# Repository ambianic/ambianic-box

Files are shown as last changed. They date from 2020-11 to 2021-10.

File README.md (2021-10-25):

# Ambianic Box



Ambianic Box is a 3D printable enclosure for Ambianic Edge. It is intended for Raspberry Pi 4B with a 5MP Raspberry Camera.

[Read the docs](https://docs.ambianic.ai/users/ambianicbox/) for more information on assembling your own Ambianic Box.

<span aligh="left">
  
  
<span>

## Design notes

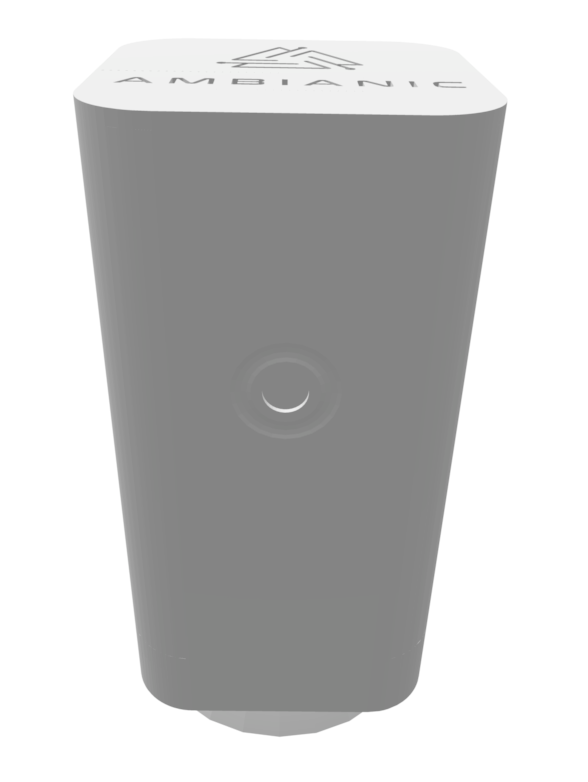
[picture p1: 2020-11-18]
ambianic_box_rendering.png

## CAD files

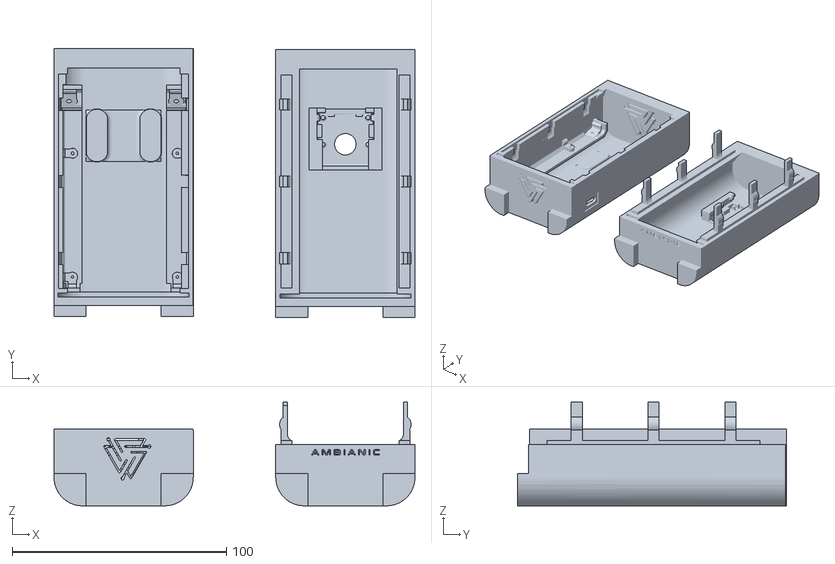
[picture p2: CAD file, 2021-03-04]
Ambianic_Box_for_Home_Care.stl
168.5 x 125.4 x 48.4

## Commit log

2020-11-18 feat: first STL prototype upload
    [Ambianic Box for Home Care.stl]
2020-11-19 fix: delete old version
    [Ambianic Box for Home Care.stl]
2020-11-19 fix: new version
    [Ambianic_Box_for_Home_Care.stl]
2020-11-19 fix: fit issues
    - make base a separate one piece that plugs in vertically. Better print and better support for front and back parts.
    - refine front and back snap shapes.
    - camera mount pins too thick. Camera board holes do not fit in.
    - adjust base pins: don't fit - too big, legs break off easily.
    - Picam mount: lens hole too small, pins too thin - slide out easily, picam board slips out from mount easily
    - Fits don't match for front and back parts
    - Audio and hdmi ports: open holes, don't match with the actual board positions
    [Ambianic_Box_for_Home_Care.stl]
2020-11-21 fix: fit and finish
    [Ambianic_Box_for_Home_Care.stl]
2020-11-21 fix: back plate openings for wall mount
    [Ambianic_Box_for_Home_Care.stl]
2020-11-21 fix: fit
    [Ambianic_Box_for_Home_Care.stl]
2020-11-21 fix: 3d fit
    [Ambianic_Box_for_Home_Care.stl]
2020-11-22 fix: fit polish
    [Ambianic_Box_for_Home_Care.stl]
2020-11-24 docs: wall mount [skip ci]
2020-11-24 docs: update mounting [skip ci]
2021-01-14 fix: expand camera opening so it doesn't detach
    [Ambianic_Box_for_Home_Care.stl]
2021-03-04 fix: tighten loose fit
    [Ambianic_Box_for_Home_Care.stl]
2021-03-08 docs: link to step by step assembly slides
2021-04-02 docs: update assembly docs link [skip ci]
